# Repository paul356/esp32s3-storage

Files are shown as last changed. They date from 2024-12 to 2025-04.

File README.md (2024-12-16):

# esp32s3-storage

这是一款基于ESP32S3的移动存储产品的PCB板，这个开源硬件项目使用开源软件KiCad8打开esp32s3-storage.kicad<sub>pro文件来浏览和修改</sub>。项目基于GPLv3，本项目不提供任何保证，但允许任意修改，但需要保持开源义务。欢迎大家提Issue或PR。

本项目使用了两个需要引入的元器件。第一个是micro-sd的封装文件new-micro-sd-socket-taobao-9-pin.kicad<sub>mod</sub>，位于项目目录中，使用footprint editor导入该文件，创建的库名是imported-footprint，footprint名字是new-micro-sd-socket-taobao-9-pin。另一个元器件是ESP32S3，通过安装espressif-kicad-addon插件获得该元器件。通过乐鑫[kicad-libraries](https://github.com/espressif/kicad-libraries)项目页面下载插件包，再打开KiCad8的Plugin and Content Manager工具，点击Install from File&#x2026;，选中下载好的插件文件，安装插件。安装好后会在Installed Tab页看到Espressif Libary。

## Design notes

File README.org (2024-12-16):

* esp32s3-storage

这是一款基于ESP32S3的移动存储产品的PCB板，这个开源硬件项目使用开源软件KiCad8打开esp32s3-storage.kicad_pro文件来浏览和修改。项目基于GPLv3，本项目不提供任何保证，但允许任意修改，但需要保持开源义务。欢迎大家提Issue或PR。

本项目使用了两个需要引入的元器件。第一个是micro-sd的封装文件new-micro-sd-socket-taobao-9-pin.kicad_mod，位于项目目录中，使用footprint editor导入该文件，创建的库名是imported-footprint，footprint名字是new-micro-sd-socket-taobao-9-pin。另一个元器件是ESP32S3，通过安装espressif-kicad-addon插件获得该元器件。通过乐鑫[[https://github.com/espressif/kicad-libraries][kicad-libraries]]项目页面下载插件包，再打开KiCad8的Plugin and Content Manager工具，点击Install from File...，选中下载好的插件文件，安装插件。安装好后会在Installed Tab页看到Espressif Libary。

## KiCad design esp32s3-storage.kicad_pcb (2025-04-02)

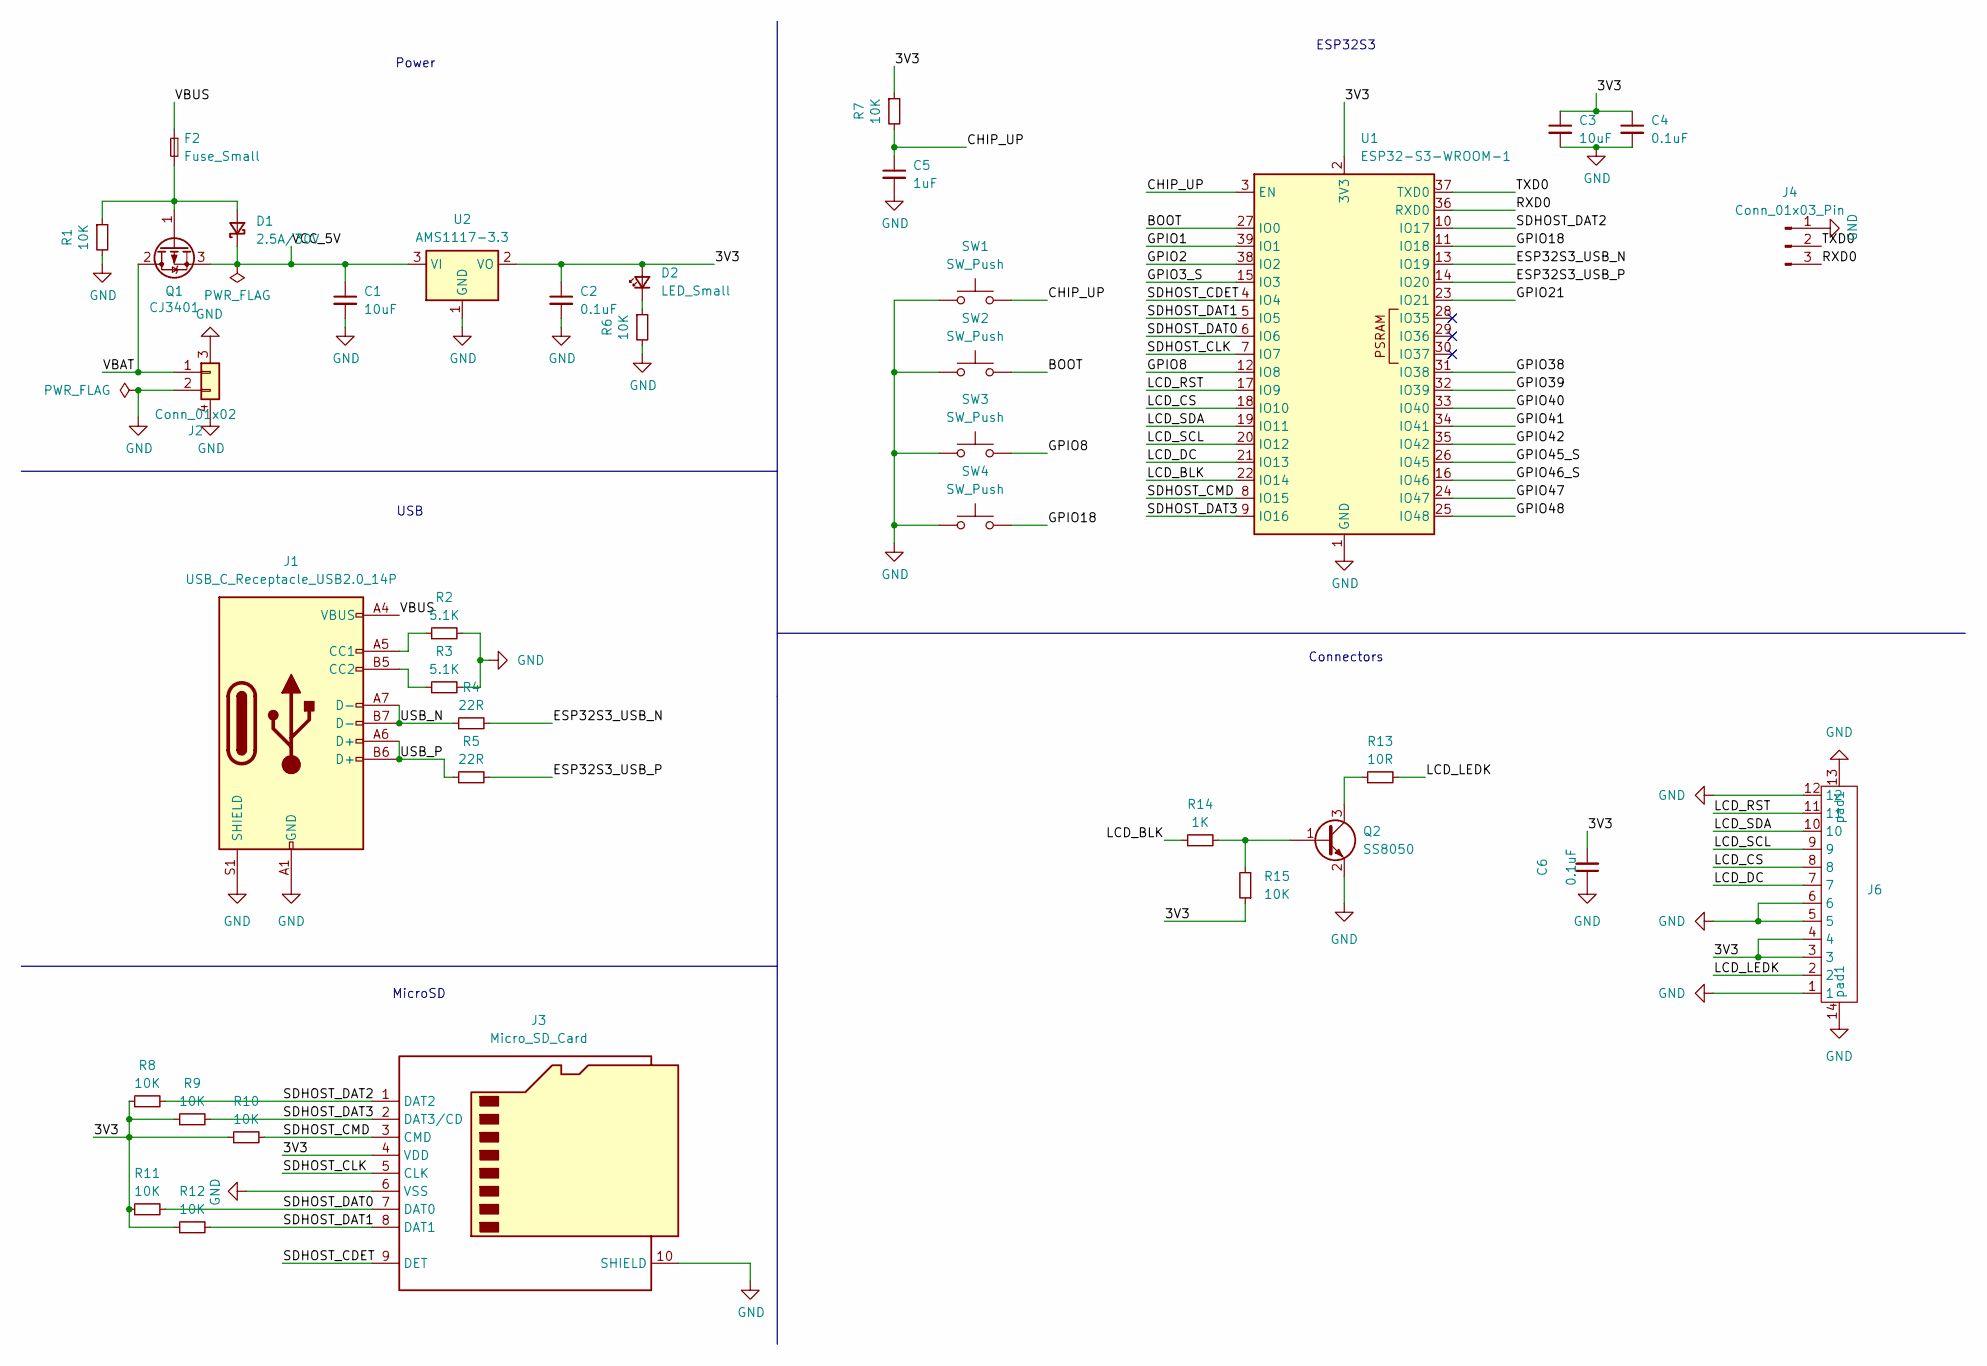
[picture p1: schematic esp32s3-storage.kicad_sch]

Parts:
C1, C3: 10uF; C_0603_1608Metric; LCSC Part # C19702
C2, C4, C6: 0.1uF; C_0603_1608Metric; LCSC Part # C14663
C5: 1uF; C_0603_1608Metric; LCSC Part # C15849
D1: 2.5A/30V; D_SOD-123; LCSC Part # C8598
D2: LED_Small; LED_0603_1608Metric; LCSC Part # C2286
F2: Fuse_Small; Fuse_0805_2012Metric; LCSC Part # C3161772
J1: USB_C_Receptacle_USB2.0_14P; USB_C_Receptacle_HRO_TYPE-C-31-M-12; LCSC Part # C2988369
J2: Conn_01x02; 1x2 pin gap 1.25mm SMD socket; LCSC Part # C2845379
J3: Micro_SD_Card; new-micro-sd-socket-taobao-9-pin; LCSC Part # C381082
J4: Conn_01x03_Pin; PinHeader_1x03_P2.54mm_Vertical
J6: JST AFC01-S12FCC-00 1x2 P0.5mm back-flip bottom-side; LCSC Part # C262268
Q1: CJ3401; SOT-23; LCSC Part # C15127
Q2: SS8050; SOT-23; LCSC Part # C2150
R1, R6, R7, R8, R9, R10, R11, R12, R15: 10K; R_0603_1608Metric; LCSC Part # C25804
R2, R3: 5.1K; R_0603_1608Metric; LCSC Part # C23186
R4, R5: 22R; R_0603_1608Metric; LCSC Part # C23345
R13: 10R; R_0603_1608Metric
R14: 1K; R_0603_1608Metric
SW1, SW2, SW3, SW4: SW_Push; SW_SPST_PTS647_Sx38; LCSC Part # C318884
U1: ESP32-S3-WROOM-1; LCSC Part # C2913204
U2: AMS1117-3.3; SOT-223-3_TabPin2; LCSC Part # C6186

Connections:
/3V3: C2.1, C3.1, C4.1, C6.2, D2.2 (A), J3.4 (VDD), J6.3, J6.4, R7.1, R8.1, R9.1, R10.1, R11.1, R12.1, R15.1, U1.2 (3V3), U2.2 (VO)
/BOOT: SW2.2, U1.27 (IO0)
/CHIP_UP: C5.1, R7.2, SW1.2, U1.3 (EN)
/ESP32S3_USB_N: R4.2, U1.13 (IO19)
/ESP32S3_USB_P: R5.2, U1.14 (IO20)
/GPIO1: U1.39 (IO1)
/GPIO2: U1.38 (IO2)
/GPIO3_S: U1.15 (IO3)
/GPIO8: SW3.2, U1.12 (IO8)
/GPIO18: SW4.2, U1.11 (IO18)
/GPIO21: U1.23 (IO21)
/GPIO38: U1.31 (IO38)
/GPIO39: U1.32 (IO39)
/GPIO40: U1.33 (IO40)
/GPIO41: U1.34 (IO41)
/GPIO42: U1.35 (IO42)
/GPIO45_S: U1.26 (IO45)
/GPIO46_S: U1.16 (IO46)
/GPIO47: U1.24 (IO47)
/GPIO48: U1.25 (IO48)
/LCD_BLK: R14.1, U1.22 (IO14)
/LCD_CS: J6.8, U1.18 (IO10)
/LCD_DC: J6.7, U1.21 (IO13)
/LCD_LEDK: J6.2, R13.2
/LCD_RST: J6.11, U1.17 (IO9)
/LCD_SCL: J6.9, U1.20 (IO12)
/LCD_SDA: J6.10, U1.19 (IO11)
/RXD0: J4.3, U1.36 (RXD0)
/SDHOST_CDET: J3.9 (DET), U1.4 (IO4)
/SDHOST_CLK: J3.5 (CLK), U1.7 (IO7)
/SDHOST_CMD: J3.3 (CMD), R10.2, U1.8 (IO15)
/SDHOST_DAT0: J3.7 (DAT0), R11.2, U1.6 (IO6)
/SDHOST_DAT1: J3.8 (DAT1), R12.2, U1.5 (IO5)
/SDHOST_DAT2: J3.1 (DAT2), R8.2, U1.10 (IO17)
/SDHOST_DAT3: J3.2 (DAT3/CD), R9.2, U1.9 (IO16)
/TXD0: J4.2, U1.37 (TXD0)
/USB_N: J1.A7 (D-), J1.B7 (D-), R4.1
/USB_P: J1.A6 (D+), J1.B6 (D+), R5.1
/VBAT: J2.1, Q1.2 (D)
/VBUS: F2.1, J1.A4 (VBUS), J1.A9 (VBUS), J1.B4 (VBUS), J1.B9 (VBUS)
/VCC_5V: C1.1, D1.1 (K), Q1.3 (S), U2.3 (VI)
GND: C1.2, C2.2, C3.2, C4.2, C5.2, C6.1, J1.A1 (GND), J1.A12 (GND), J1.B1 (GND), J1.B12 (GND), J1.S1 (SHIELD), J2.2, J2.3, J2.4, J3.6 (VSS), J3.10 (SHIELD), J4.1, J6.1, J6.5, J6.6, J6.12, J6.13 (pad1), J6.14 (pad1), Q2.2 (E), R1.2, R2.2, R3.2, R6.2, SW1.1, SW2.1, SW3.1, SW4.1, U1.1 (GND), U1.40 (GND), U1.41 (GND), U2.1 (GND)
unnamed: D1.2 (A), F2.2, Q1.1 (G), R1.1
unnamed: D2.1 (K), R6.1
unnamed: J1.A5 (CC1), R2.1
unnamed: J1.B5 (CC2), R3.1
unnamed: Q2.1 (B), R14.2, R15.2
unnamed: Q2.3 (C), R13.1

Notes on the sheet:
USB
Connectors
MicroSD
ESP32S3
Power

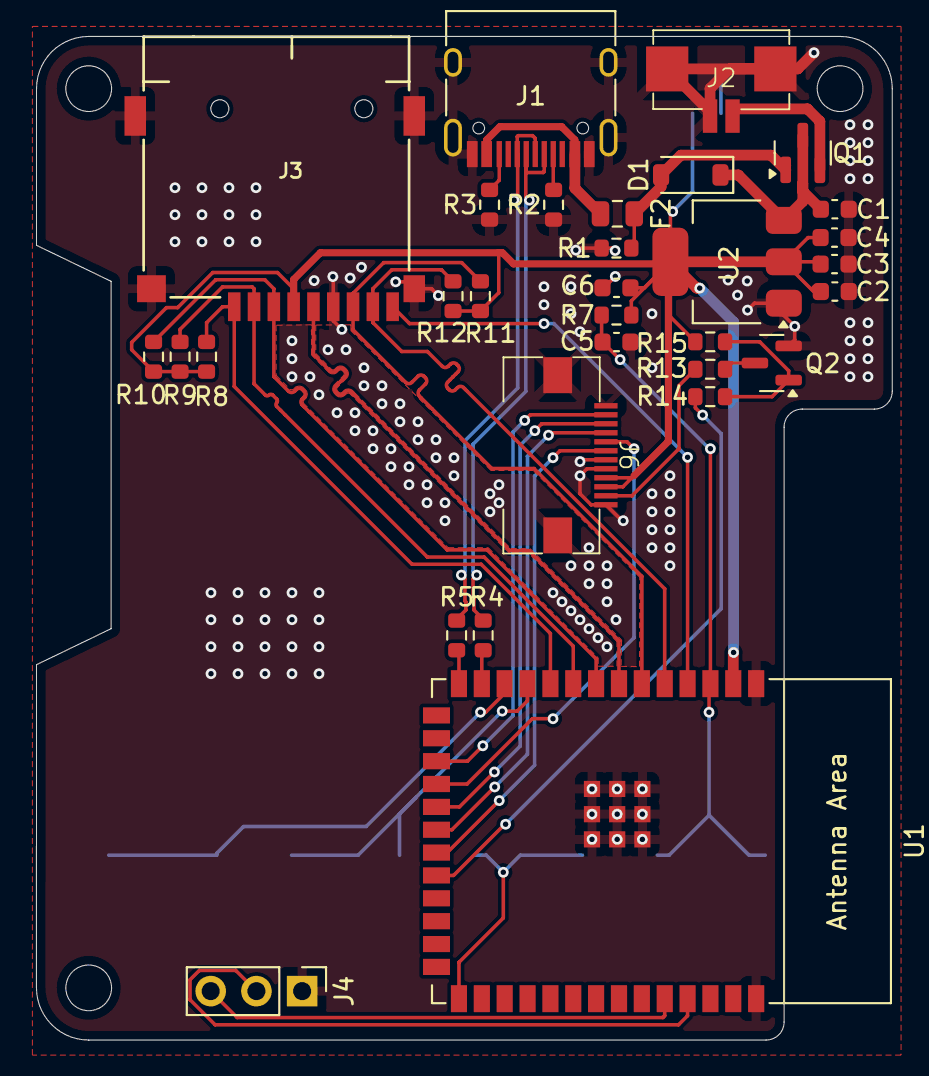
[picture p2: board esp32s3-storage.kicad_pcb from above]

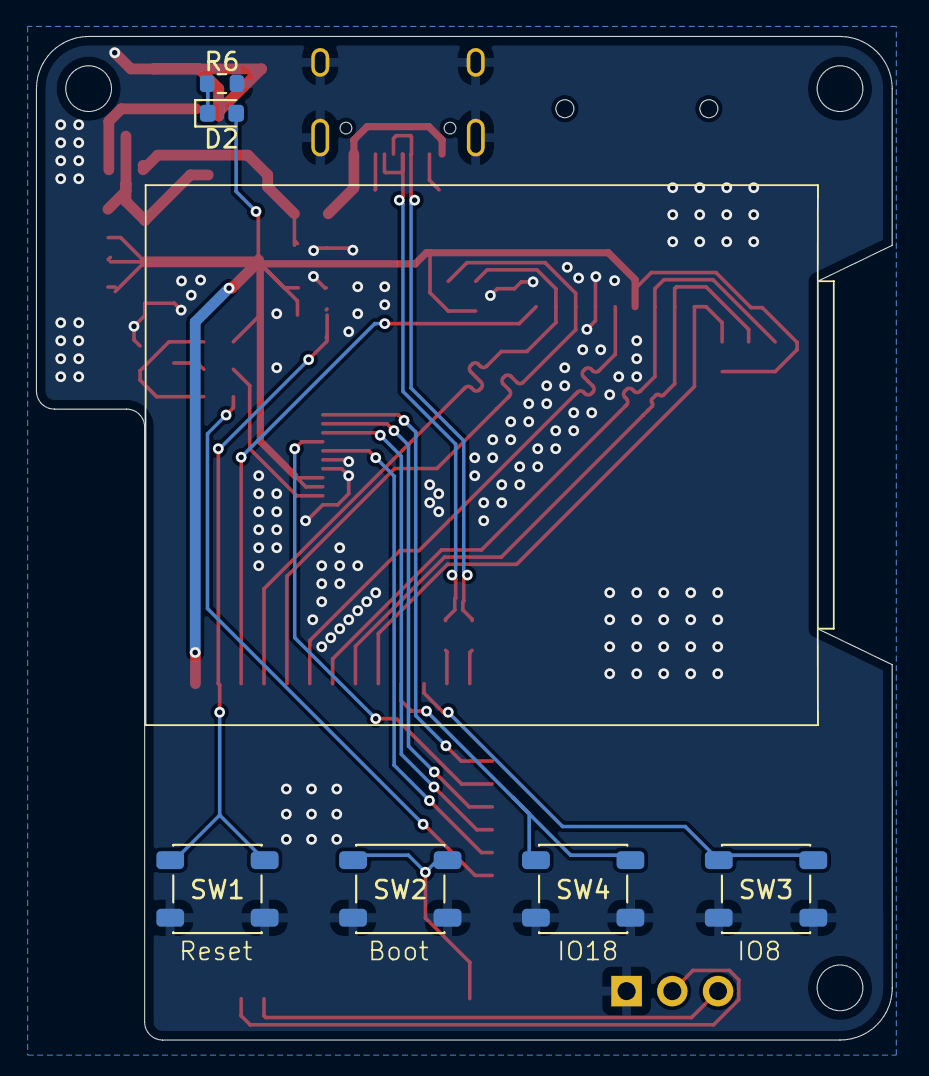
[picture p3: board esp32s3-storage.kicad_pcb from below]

Board: 2 copper layers, 47.5 x 55.8 mm, 37 parts (6 on the bottom side), 35 nets.

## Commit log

2024-12-16 baseline for esp32-storage version 0.1
    [esp32s3-storage.kicad_pcb, esp32s3-storage.kicad_sch]
2025-01-21 begin modify pcb layout
    [esp32s3-storage.kicad_pcb, esp32s3-storage.kicad_sch]
2025-01-23 The second version of esp32s3 storage. Becare of the SDIO pins which are changed!
    [esp32s3-storage.kicad_pcb, esp32s3-storage.kicad_sch]
2025-01-23 add silk to switches
    [esp32s3-storage.kicad_pcb]
2025-03-12 esp32s3-storage v3
    [esp32s3-storage.kicad_pcb, esp32s3-storage.kicad_sch]
2025-03-21 esp32s3-storage v4
    [esp32s3-storage.kicad_pcb, esp32s3-storage.kicad_sch]
2025-04-01 esp32s3-storage v5
    [esp32s3-storage.kicad_pcb, esp32s3-storage.kicad_sch]
2025-04-01 Reposition two value texts on the paste layer
    [esp32s3-storage.kicad_pcb]
2025-04-01 Add the sn for fpc socket
    [esp32s3-storage.kicad_pcb, esp32s3-storage.kicad_sch]
2025-04-02 Update sn for type-c socket and fuse
    [esp32s3-storage.kicad_pcb]
2025-04-02 add sn for fuse and type-c usb
    [esp32s3-storage.kicad_sch]
